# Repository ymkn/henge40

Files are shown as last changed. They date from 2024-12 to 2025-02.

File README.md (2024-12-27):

# Henge40

A compact 40% keyboard with 12-column row staggered layout in 12.75u width.

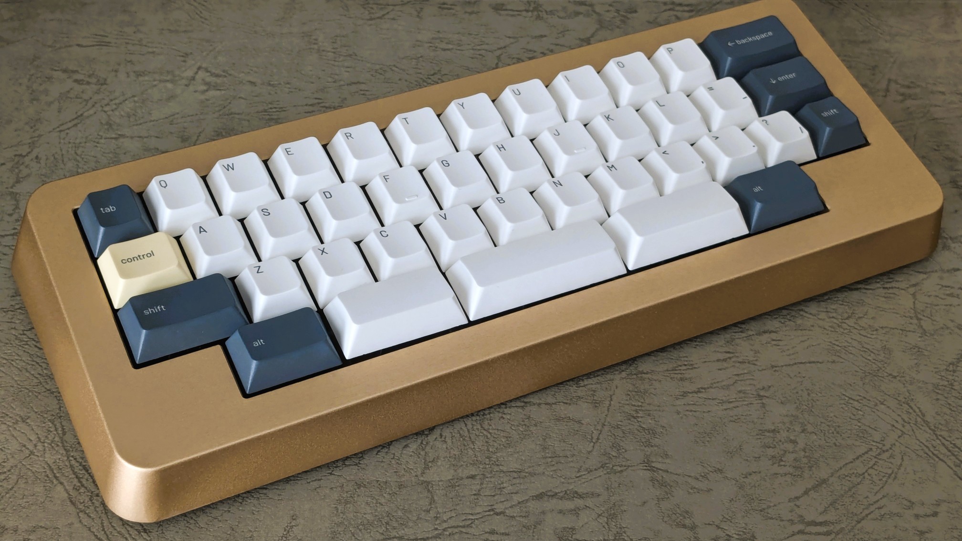
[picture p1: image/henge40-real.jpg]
Henge40 real image


This keyboard was inspired by [Menhir](https://fruitykeeb.xyz/collections/menhir-collection/products/gb-menhir).

## Default Layout

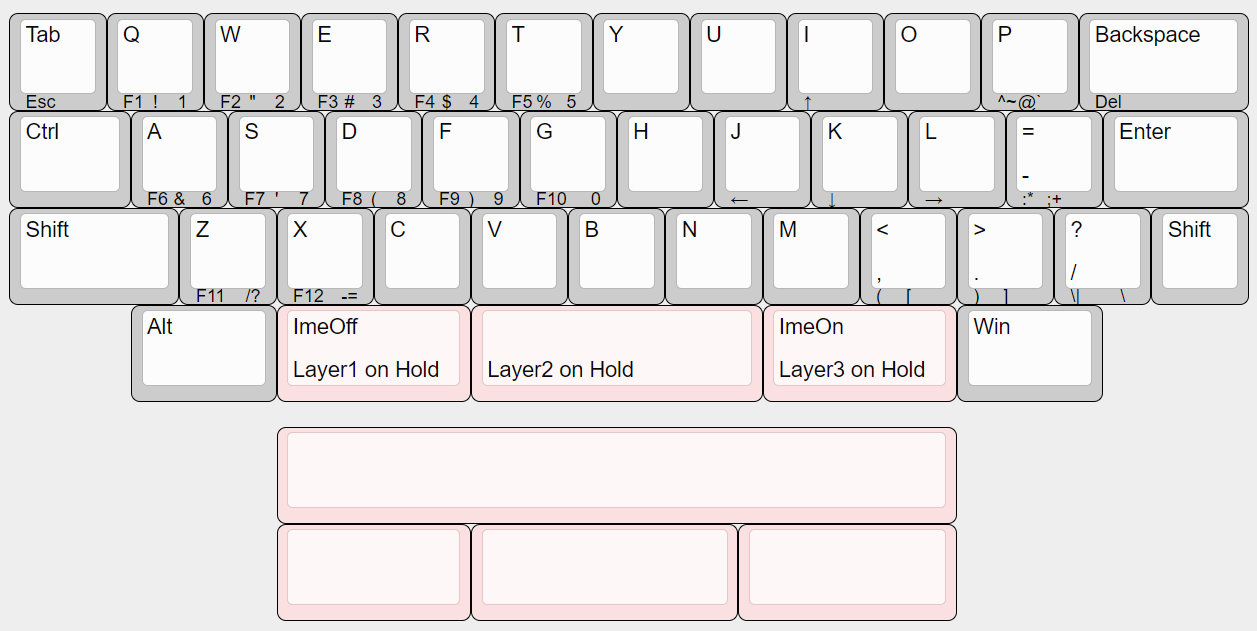
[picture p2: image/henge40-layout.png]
Henge40 layouts


You can also customize the layout using [Vial](https://get.vial.today/).

## Build Guide

See [Build Guide](doc/buildguide.md).

## License

This project is licensed under the MIT License, see the [LICENSE file](LICENSE) for details.

However, this does not apply to logo data (image files, KiCAD footprints, etc.) included in the resources of this project. Please contact us for secondary use.

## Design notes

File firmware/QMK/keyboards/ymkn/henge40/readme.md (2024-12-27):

# Henge40

Henge40 - A compact 40% keyboard with 12-column row staggered layout in 12.75u width.

* Keyboard Maintainer: [ymkn](https://github.com/ymkn)

Make example for this keyboard (after setting up your build environment):

    make ymkn/henge40:vial

Flashing example for this keyboard:

1. Enter the bootloader.
2. Simply copy ymkn_henge40_vial.uf2 to RPI_RP2 drive.

This keyboard supports [Vial](https://get.vial.today/) configurator.

## Bootloader

Enter the bootloader in 2 ways:

* **Bootmagic reset**: Hold down the key at (0,0) and (1,11) in the matrix (usually the top left key or Tab and the right 2nd top key or Enter) and plug in the keyboard
* **Physical reset button**: Briefly press the button on the daughterboard

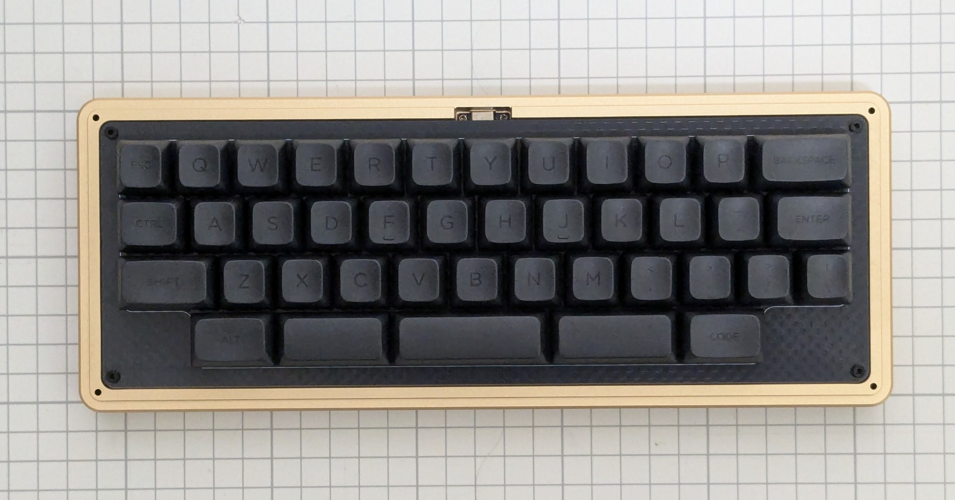
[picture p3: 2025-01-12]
image/henge40-keycap.jpg

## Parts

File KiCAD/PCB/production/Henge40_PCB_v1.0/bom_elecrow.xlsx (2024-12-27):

*Reference | *Manufacturer Part number | *QTY | *Original | Description | Purchase Link
D1, D10, D11, D12, D13, D14, D15, D16, D17, D18, D19, D2, D20, D21, D22, D23, D24, D25, D26, D27, D28, D29, D3, D30, D31, D32, D33, D34, D35, D36, D37, D38, D39, D4, D40, D41, D5, D6, D7, D8, D9 | 1N4148W | 41 | N
SW1, SW2, SW3, SW10, SW11, SW12, SW13, SW14, SW15, SW16, SW17, SW18, SW19, SW20, SW21, SW21_1, SW22, SW23, SW24, SW25, SW26, SW27, SW28, SW29, SW30, SW31, SW31_1, SW32, SW33, SW34, SW35, SW36, SW37, SW38, SW39, SW4, SW40, SW41, SW5, SW6, SW7, SW8, SW9 | CPG151101S11 | 43 | N | SKU: CRP13070O | https://www.elecrow.com/kailh-pcb-socket-sip-socket-hot-swappable-hot-plug-cpg151101s11-for-mechanical-keyboard.html
Declare：
All ICs will be original even you selected Not original required.
Original: Y means must use the original brand model, N means that you can accept the substitutes with same spec

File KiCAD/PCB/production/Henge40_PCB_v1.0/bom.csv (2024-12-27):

Designator | Footprint | Quantity | Value | LCSC Part #
D1, D10, D11, D12, D13, D14, D15, D16, D17, D18, D19, D2, D20, D21, D22, D23, D24, D25, D26, D27, D28, D29, D3, D30, D31, D32, D33, D34, D35, D36, D37, D38, D39, D4, D40, D41, D5, D6, D7, D8, D9 | D_SOD-123 | 41 | 1N4148W
SW1, SW10, SW11, SW12, SW13, SW14, SW15, SW16, SW17, SW18, SW19, SW20, SW21, SW21_1, SW22, SW23, SW24, SW25, SW26, SW27, SW28, SW29, SW30, SW31, SW31_1, SW32, SW33, SW34, SW36, SW37, SW38, SW4, SW41, SW5, SW6, SW8, SW9 | SW_MX_HS_CPG151101S11_1u | 37 | SW_Push
SW2 | SW_MX_HS_CPG151101S11_1.25u | 1 | SW_Push
SW3, SW39 | SW_MX_HS_CPG151101S11_1.75u | 2 | SW_Push
SW35, SW40, SW7 | SW_MX_HS_CPG151101S11_1.5u | 3 | SW_Push

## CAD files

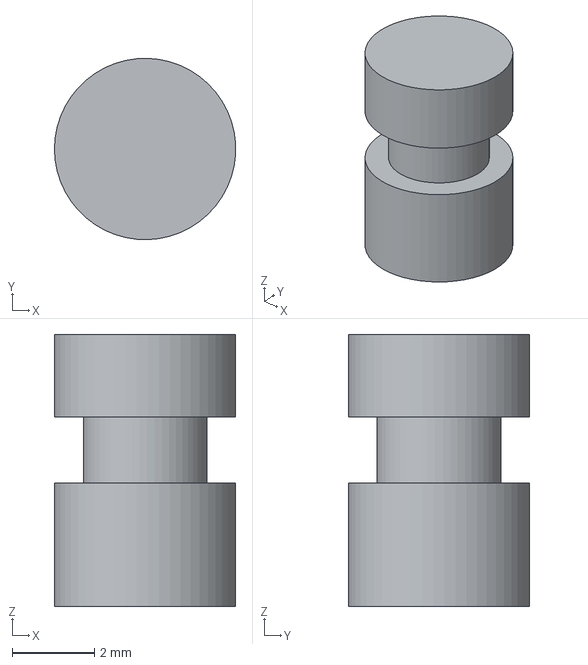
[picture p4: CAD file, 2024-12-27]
FreeCAD/DampingBall-Body.step
4.40 x 4.40 x 6.60 mm

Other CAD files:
FreeCAD/DampingBall.FCStd

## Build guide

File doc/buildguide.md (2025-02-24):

# Henge40ビルドガイド

## 1. 本書について

本書は自作キーボードHenge40キットのビルドガイドです。

## 2. 準備

### 2.1 内容物の確認

製品到着後すぐに内容物を確認し、不足や破損があった場合は保証期間内に[お問い合わせ先](https://ymkn.github.io/1u-nekokey/support/)までお寄せください。

※販売品に注記がある場合はそちらを正としてください。

|番号|品目|数量|
|---|---|---|
|1|Henge40 スイッチプレート|1枚|
|2|Henge40 メイン基板|1枚|
|3|Henge40 ドーターボード|1枚 (取付済)|
|4|Henge40 ケース (ボトム/トップ)|1セット|
|5|Henge40 スイッチフォーム|1枚|
|6|Henge40 スイッチパッド|1枚|
|7|Henge40 ケースフォーム|1枚|
|8|FPCケーブル 150mm 8ピン 1mmピッチ|1+1(予備)本|
|9|M2ねじ 4mm|8個 (取付済)|
|10|Damping Ball|4個 (取付済)|
|11|ゴム足（小）|4個|
|12|ゴム足（大） ※Flatケースにのみ付属|2個|

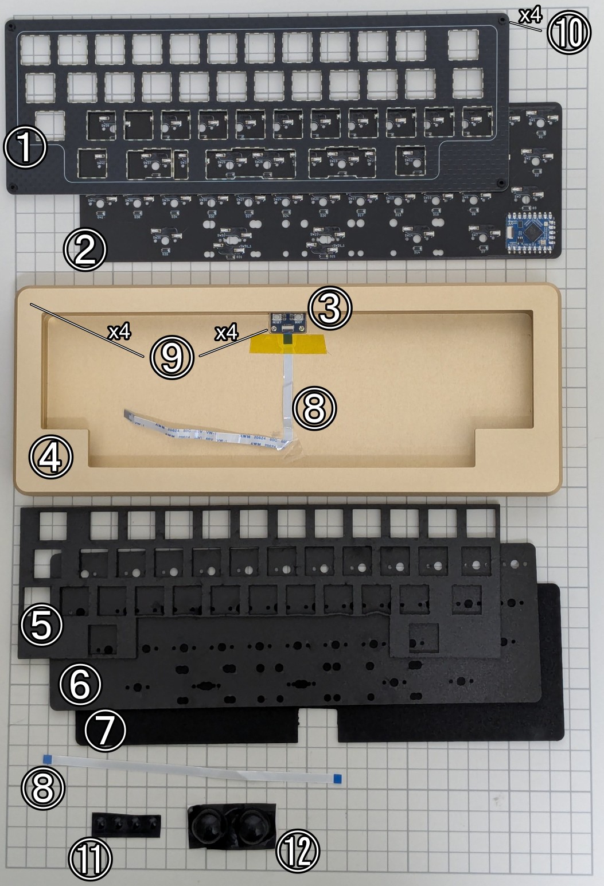
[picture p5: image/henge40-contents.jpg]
Henge40内容物


### 2.2 別途用意が必要な部品

下記は本キットに含まれません。国内外の自作キーボード専門店や電子部品販売店などから別途調達してください。

|品目|数量|備考|
|---|---|---|
|MX互換キースイッチ|39-41|[Cherry MX](https://www.cherry.de/en-gb/gaming/developer)もしくはその互換品|
|MX互換キーキャップ|必要数|[Cherry MX](https://www.cherry.de/en-gb/gaming/developer)もしくはその互換品|
|2uサイズPCBマウント型スタビライザー|2-3|幅の広いキーの押し下げを安定させる部品です。最下段で2u/2.75uキーを使う場合に必要です|
|3uサイズPCBマウント型スタビライザー|1|幅の広いキーの押し下げを安定させる部品です。最下段で3uキーを使う場合に必要です|
|7uサイズPCBマウント型スタビライザー|1|幅の広いキーの押し下げを安定させる部品です。最下段で7uキーを使う場合に必要です|

### 2.3 適合するキーキャップサイズ

下図の通りのキーキャップが必要です。赤網掛け部分は入れ替え可能な部分です。

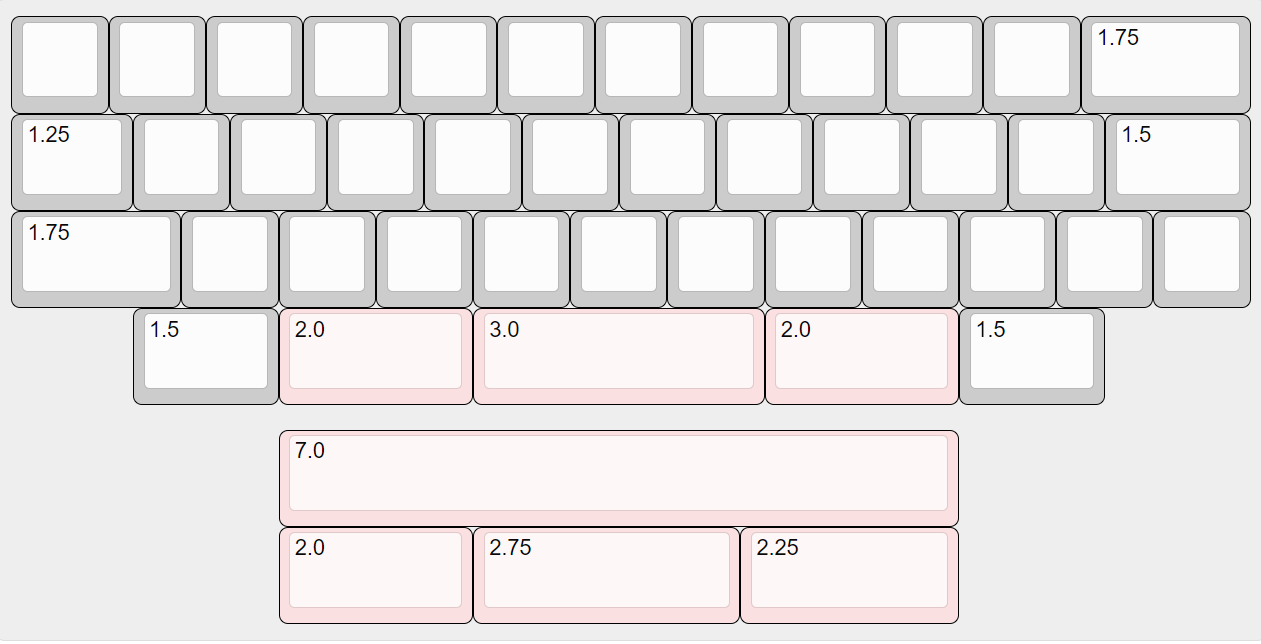
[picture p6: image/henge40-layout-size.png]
レイアウト


一般的なキーキャップセットには含まれないサイズがありますのでご購入の際はご注意ください。特に下記サイズは標準的なキーキャップセットに加えて別途40%用のキーキャップセットを入手する必要があります。

|行|サイズ|初期レイアウトの対応キー名|
|---|---|---|
|R1| - |※本キーボードにR1行はありません。最上段はR2行となります|
|R2|1u|Tabキー|
|R2|1.75u|Backspaceキー|
|R3|1.25u|Controlキー|
|R3|1.5u|Enterキー|
|R4|1.75u|Shiftキー|
|R4|1u|Shiftキー|
|R4|2u x 2, 2.75u, 3u, 7u|スペースキー|

上に示したキー名はあくまで初期レイアウトのもので、これはお好みに変更可能です。また、キーキャップの印字はただの飾りですので、同じ行の同じサイズのキーキャップであれば異なる印字のキーキャップでもお使いいただけます。

> [!TIP]
> 自分でデザインしたキーキャップセットを購入できるサービス[YUZU Custom Keycaps](https://yuzukeycaps.com/)の40%キットにて、必要なキーが全て揃います。参考までに作者が展示用にデザインした[Henge40 Yozora](https://yuzukeycaps.com/c/3475d350-a4f5-4abe-b16b-a6b00855d77e)テンプレートをカスタマイズして発注するのも良いかと思います。

### 2.3 道具

以下の道具が必要です。

|品目|数量|備考|
|---|---|---|
|ねじ回し（プラス、M2用1番）|1|ケースを固定する際に用います|

## 4. 組み立て

### 4.1 メイン基板の準備

> [!CAUTION]
> まず作業を始める前に、メイン基板のウラ面にあるFPCケーブルコネクタの羽が水平方向に閉じていることを確認します。これが垂直方向に開いた状態で後続の作業を行うと羽が破損する可能性があります。
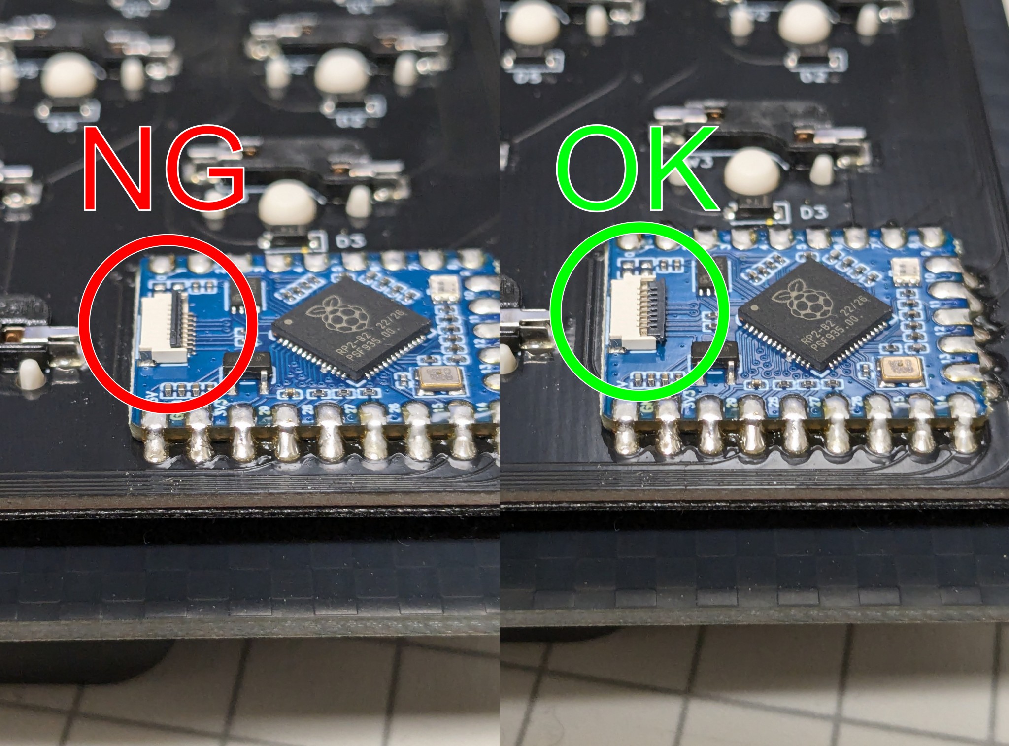
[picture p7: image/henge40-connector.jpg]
> 
> ロットによっては羽が内側ではなく外側に付いている場合もあります。こちらも同様に水平方向に閉じていることを確認してください。
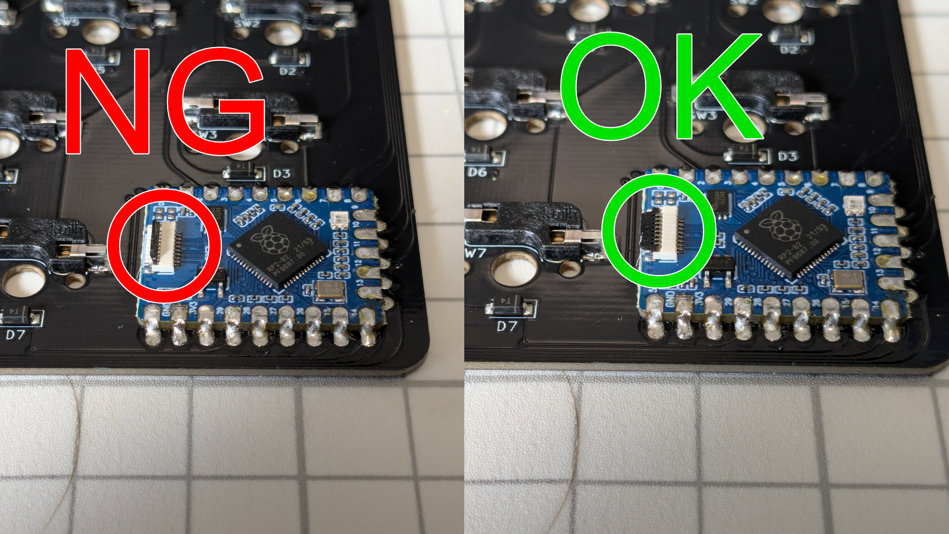
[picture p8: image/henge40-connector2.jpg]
> 

確認出来たら、**オモテ面**が上になるようにメイン基板を作業場所に配置します。

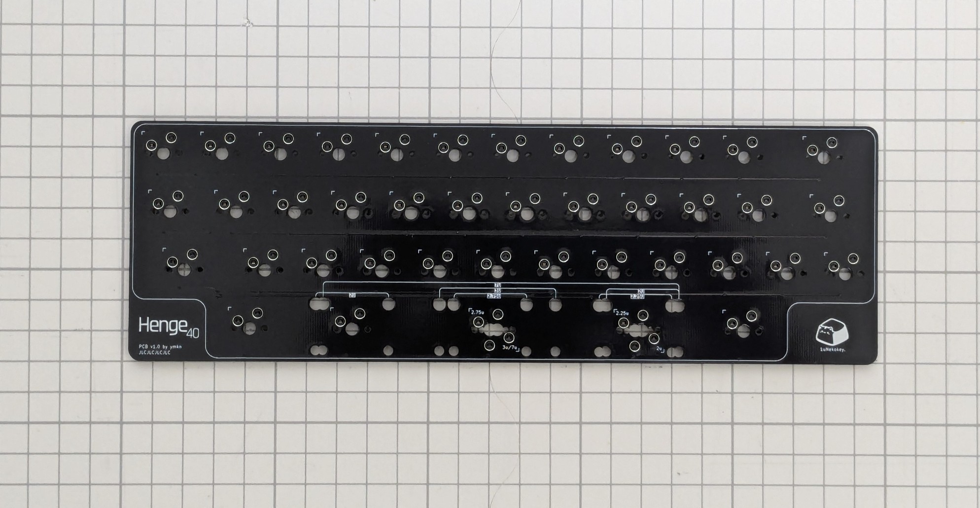
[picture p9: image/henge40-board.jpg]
基板表


### 4.2 スイッチパッドの取り付け

スイッチパッドを基板の上に設置してください。スイッチパッドと基盤の穴の位置を合わせて単純に乗せるだけでよいです。

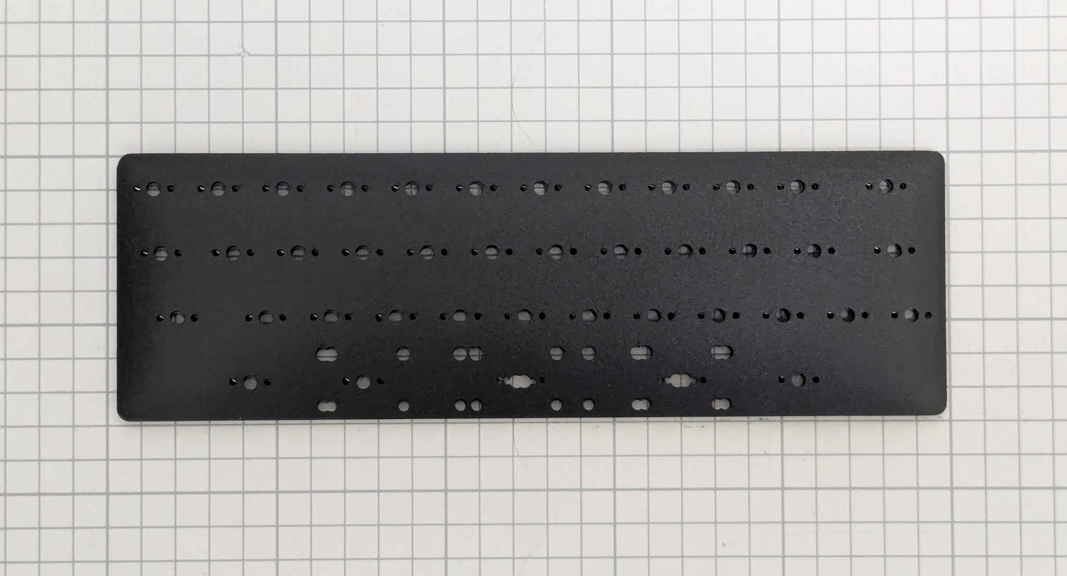
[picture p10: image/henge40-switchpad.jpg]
スイッチパッド


> [!TIP]
> スイッチパッドは打鍵音を低音寄りに変化させるための部品です。取り付けは任意ですが、取り付けない場合は1.2mm厚基板用スタビライザーを用いるか、1.6mm厚基板用スタビライザーにシム（0.4mm）を挟んで高さを調節してください。

### 4.3 スタビライザーの取り付け

スイッチパッドの上からスタビライザーを取り付けます。

取り付け位置はレイアウトによって異なります。メイン基板上のガイドを参照してください。

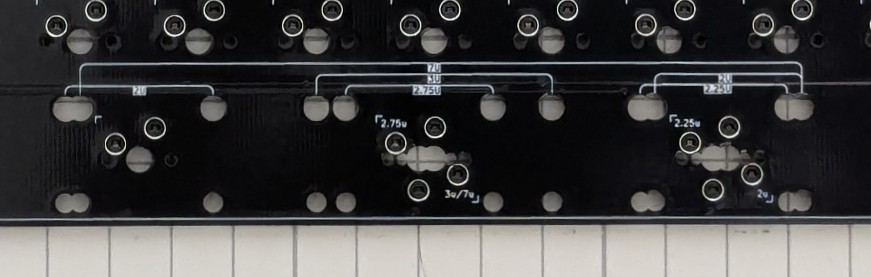
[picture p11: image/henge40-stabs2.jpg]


取り付け方はスタビライザーの説明書や世間の情報を参照ください。一般には大きい穴の方にツメを引っかけ、小さい穴の方にプッシュピンを差し込む、もしくはネジ留めを行うものが多いです。

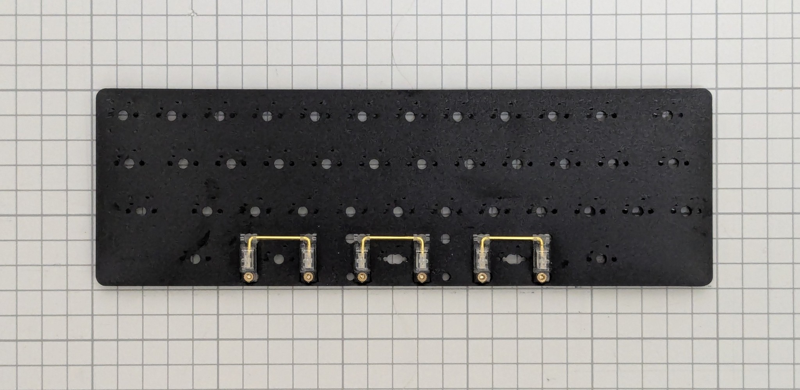
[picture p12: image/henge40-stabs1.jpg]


### 4.4 スイッチフォームの取り付け

スイッチパッドの上にスイッチフォームを乗せます。フォームの穴とスイッチの設置箇所が合う向きにしてください。

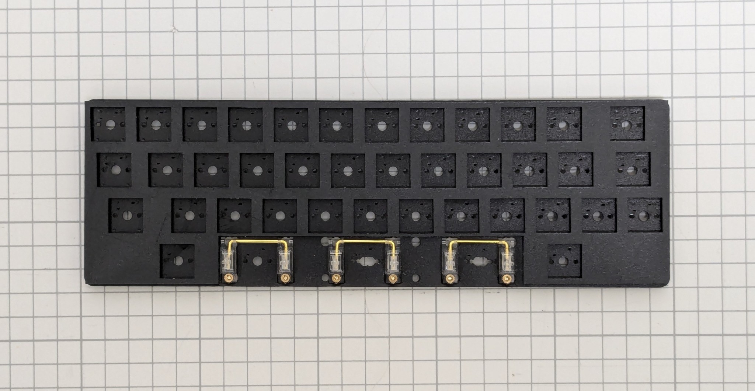
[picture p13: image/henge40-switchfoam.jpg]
スイッチフォーム


> [!TIP]
> スイッチフォームは打鍵音を小さくし反響音を抑えるための部品です。取り付けは任意です。

### 4.5 スイッチとスイッチプレートの取り付け

スイッチフォームの上にスイッチプレートを乗せ、その上からスイッチを基板のソケットに差し込みます。

差し込む前にスイッチの向きをよく確認してください。ほとんどのスイッチは南向き（ピンがキーボードの奥側向き）ですが、採用レイアウトによっては最下段に北向きの場所があります。誤った向きに押し込んでピンを曲げてしまった場合は、ラジオペンチなどで伸ばしてください。

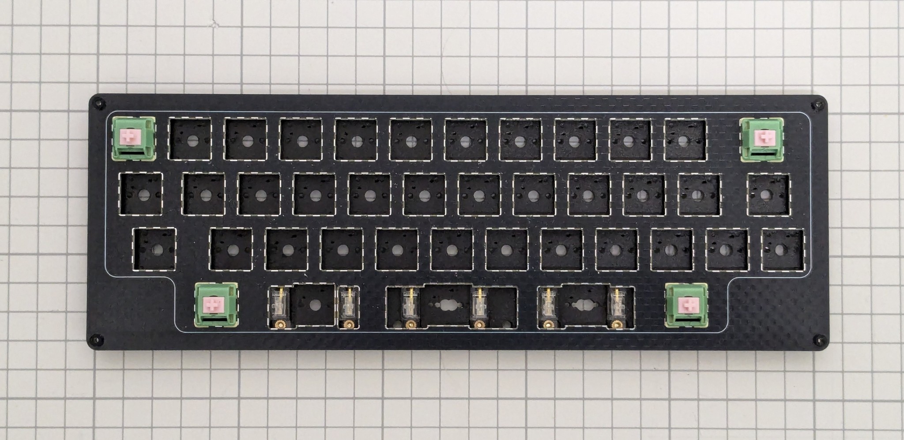
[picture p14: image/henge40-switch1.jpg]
スイッチ取り付け1


先に四隅に取り付けると作業しやすいです。

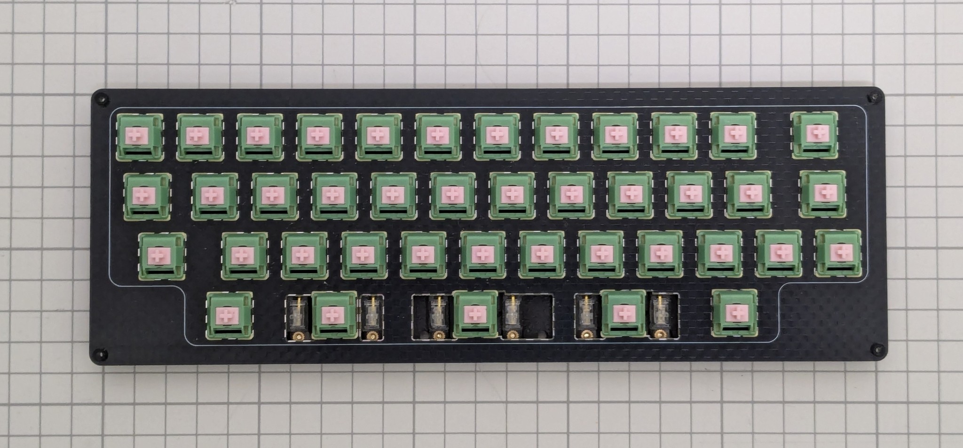
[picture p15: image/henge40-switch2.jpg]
スイッチ取り付け2


### 4.6 ケースフォームの取り付け

ケース底面四隅のネジをはずして、ケースの蓋を外します。切り欠きの位置を合わせてケースに乗せてください。

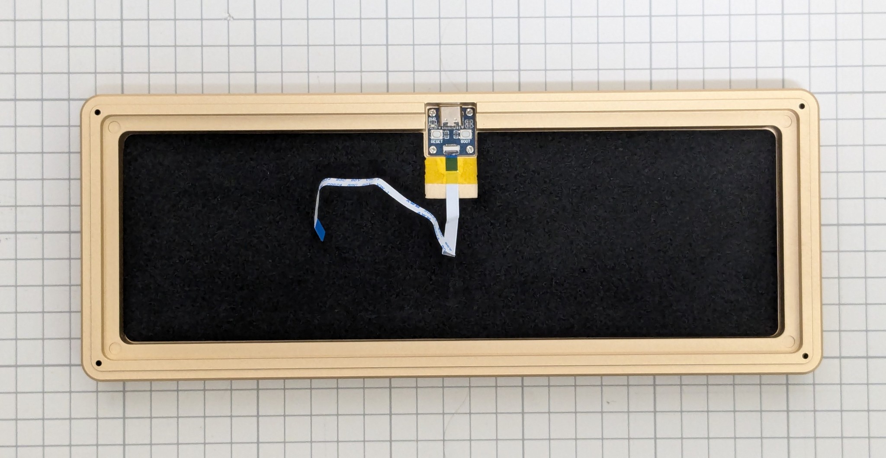
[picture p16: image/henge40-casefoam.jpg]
ケースフォーム


> [!TIP]
> ケースフォームは打鍵音の反響を抑えるほか、万一基盤とケースが触れた場合のショートを防止する役割があります。打鍵音の調整のために取り付けない場合は、代わりに絶縁可能な素材を敷いてください。

なお、ドーターボードの上に保護用フォームが取り付けてある場合は取り除いてください。

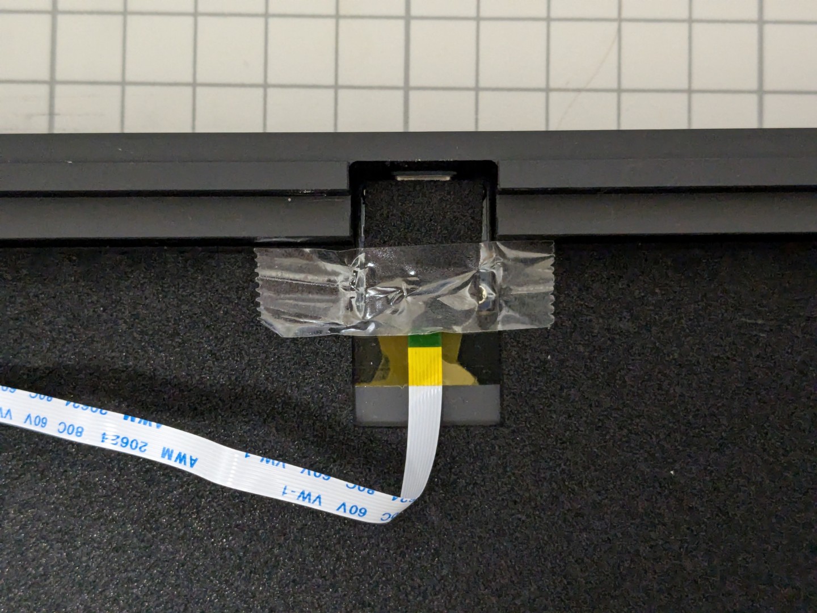
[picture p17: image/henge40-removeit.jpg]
保護フォーム


### 4.7 メイン基板とドーターボードの接続

メイン基板とドーターボードをFPCケーブルで接続します。

> [!WARNING]
> FPCケーブルを接続する**コネクタは非常に壊れやすい**部分です。無理な力を加えないように注意して作業してください。コネクタを折ってしまった場合はケーブル接続が不可能となり、キーボードとして使用できなくなってしまいます。

FPCコネクタ（黒い羽根）を垂直に立つように跳ね上げます。

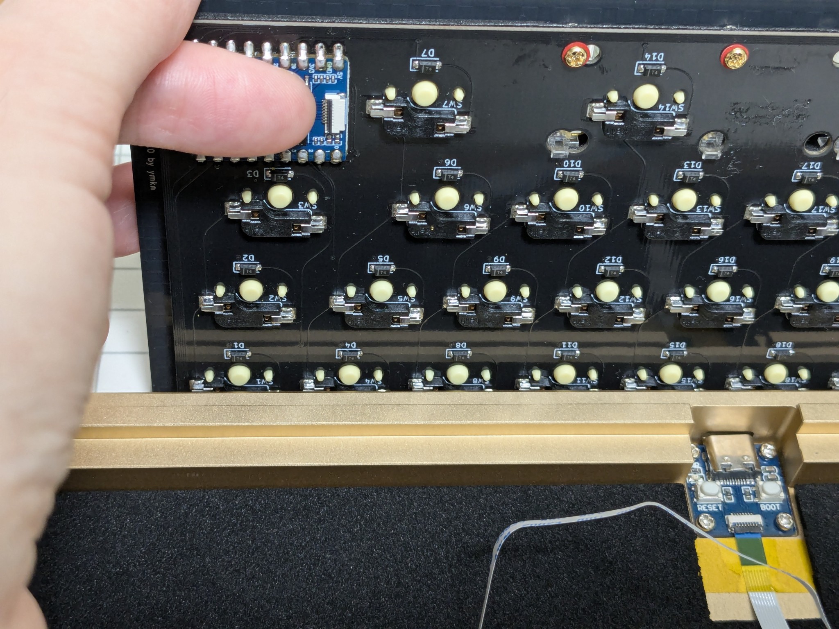
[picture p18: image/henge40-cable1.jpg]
FPC接続1


FPCケーブルの青色の面を上にしてコネクタに差し込みます（1mm弱ほどは刺さるはずです）。

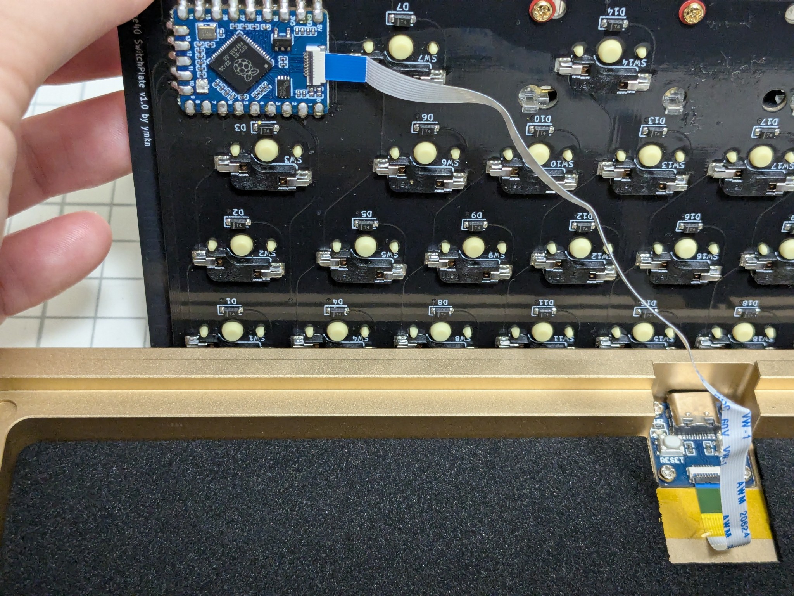
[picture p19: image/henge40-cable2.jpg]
FPC接続2


ケーブルがまっすぐに刺さっていることを確認し、コネクタの羽を元に戻して固定します。ケーブルを軽く引っ張って、抜けないことを確認してください。

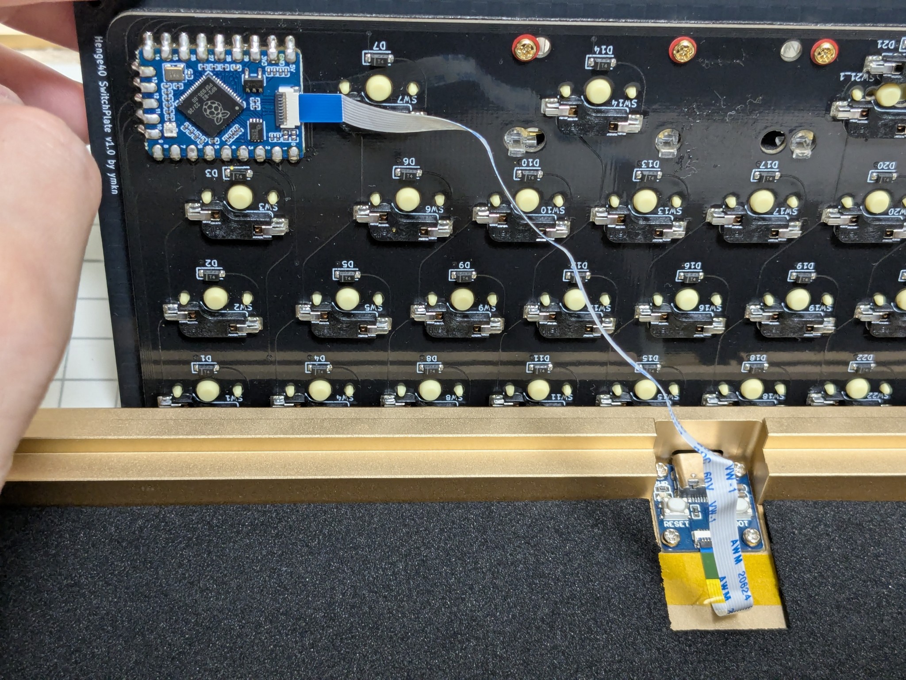
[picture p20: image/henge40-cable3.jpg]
FPC接続3


> [!TIP]
> ここでFPCケーブルをメイン基板にテープ等で固定しておくと、打鍵時にケーブルがメイン基板にぶつかってカチャカチャ音が鳴るのを防げます。
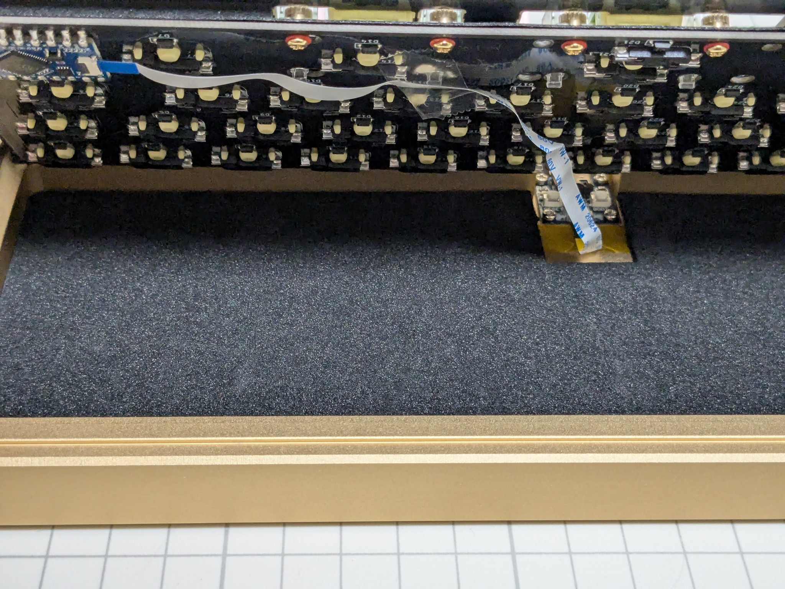
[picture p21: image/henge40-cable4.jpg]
FPC接続4


ケーブルが接続できたら、メイン基板をケースの上に置いてください。スイッチプレート四隅のゴム足が、ケースの丸い溝に入るようにします。

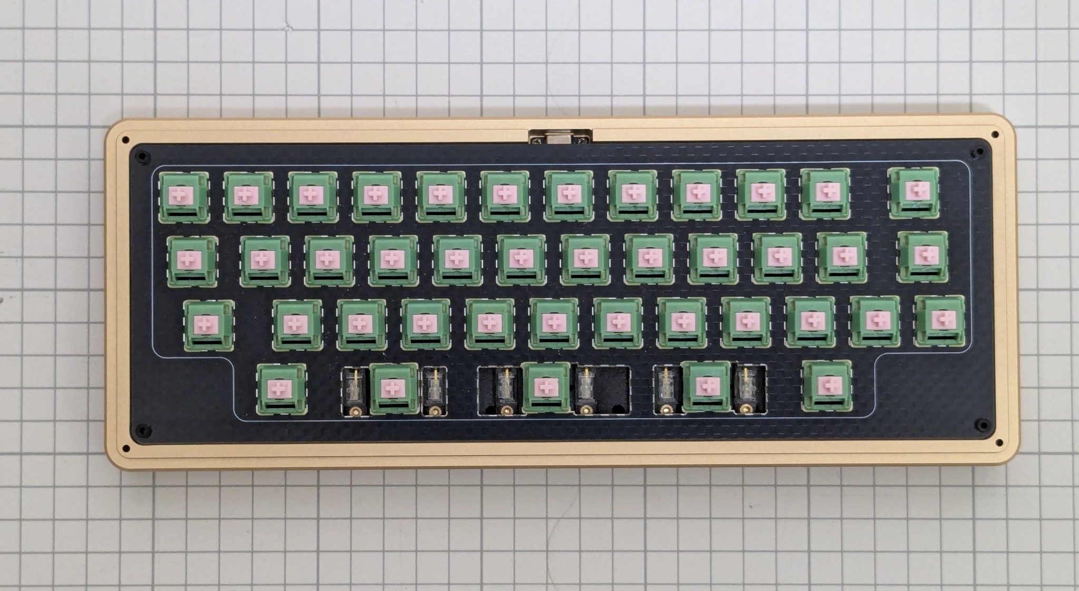
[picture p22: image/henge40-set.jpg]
ケースに設置


### 4.8 ケースのネジ留め

> [!CAUTION]
> ケースをひっくり返す際にうっかり基板を落下させてしまうと、ケーブルが強く引っ張られてコネクタを破損させてしまう可能性があります。そうならないよう慎重に行ってください。

上蓋と基板が落下しないように支えながらケースをひっくり返し、ケース底部四隅の穴にネジを入れてネジ留めを行ってください。

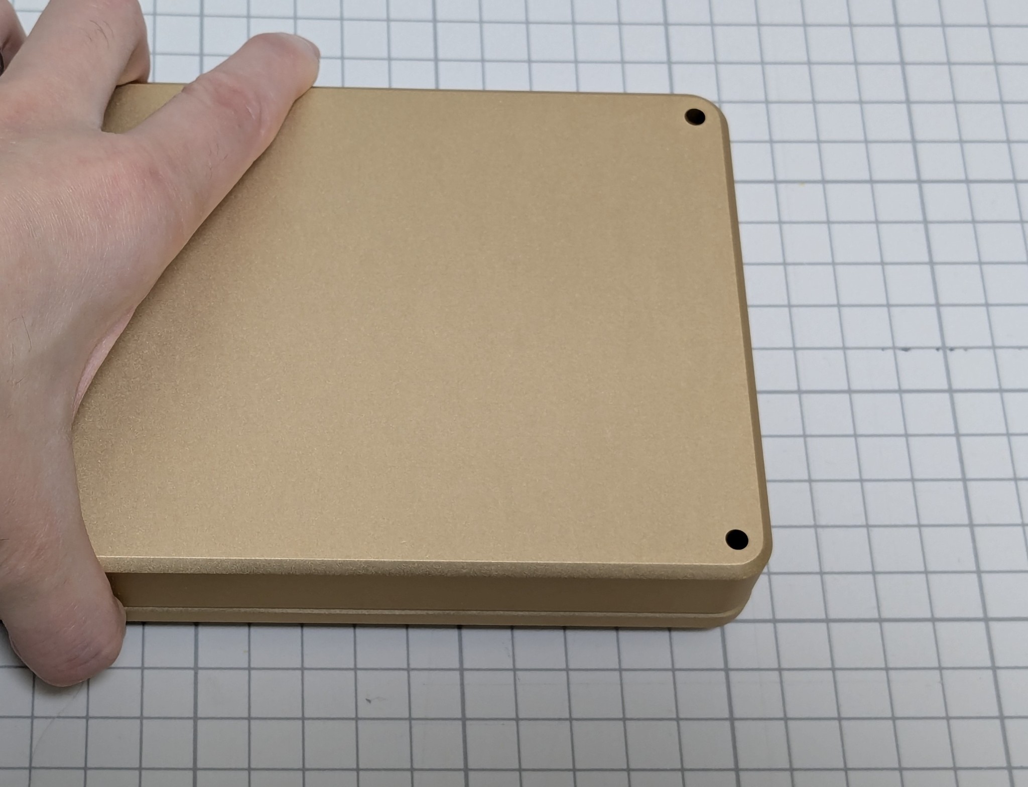
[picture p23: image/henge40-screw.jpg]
ケースのネジ留め


このとき、強い力でネジを締めつけ過ぎないように注意してください。軽い力でネジを回していって、抵抗感が増して動きにくくなるあたりで十分です。

ネジが締まったら、お好みでゴム足を取り付けてください。

### 4.10 キーキャップの取り付け

ケースの向きをもとに戻し、全てのスイッチにキーキャップを取り付けてください。

> [!TIP]
> スタビライザーのあるキーキャップは、深く押し込み過ぎると戻りにくくなることがあります。スイッチのある中央部分だけを押し込んで取り付けるようにするとよいでしょう。

すべて取り付けられたら完成です。

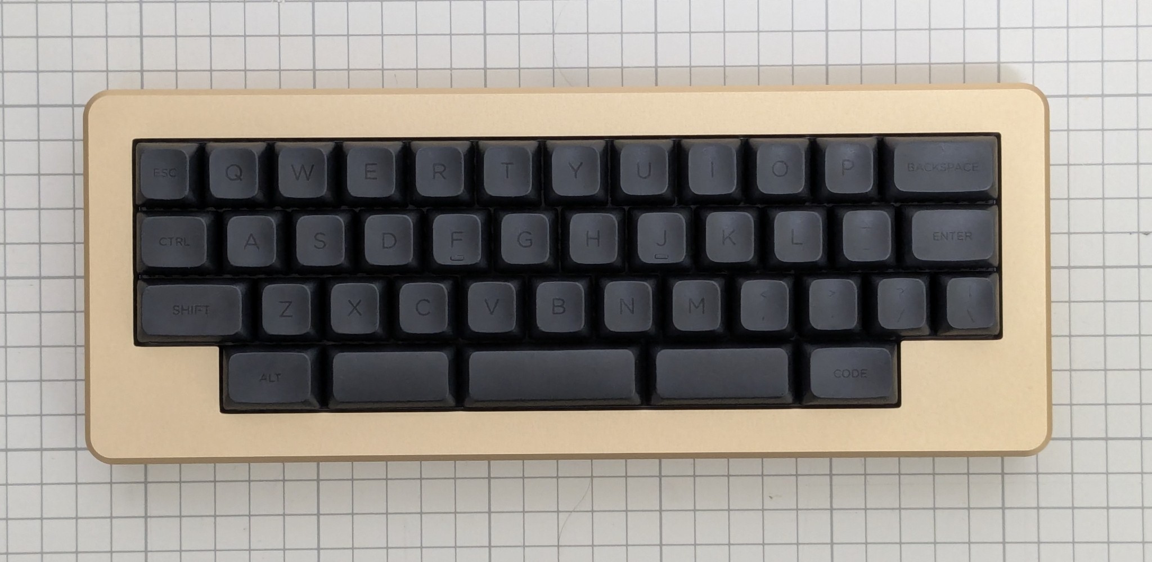
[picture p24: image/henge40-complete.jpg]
完成


## 5. 使用

### 5.1 動作確認

コンピュータとHenge40をUSBケーブルで接続し、キーボードとして認識され、文字が入力できることを確認してください。

キーボードとして認識されない場合は、FPCケーブルが外れていたりズレていたりする可能性があります。メイン基板側とドーターボード側の両方が適切に接続されていることを確認してください。また、FPCケーブルを何度も強く曲げた場合など断線している可能性があります。そのような場合は予備のケーブルに交換してください。

一部のキーのみ反応しない場合は、そのキースイッチを抜いて、スイッチのピンが曲がっていないか確認してから挿し直してみてください。ピンが曲がっていない場合でも接触が悪いせいで動かないケースもあります。

### 5.2 キーマップのカスタマイズ

本キーボードは[Vial](https://get.vial.today/)というキーマップ変更ツールに対応しています。Vialの詳しい使いかたはVialのドキュメント等を参考にしてください。

> [!TIP]
> 何らかの理由で既定のレイアウトに戻したい場合は、本書末尾記載の「ブートモードの入り方」に従いブートモードに入った後、再度USBケーブルを抜き差しすることで初期化されます。

## 6. その他

### 6.1 ブートモードの入り方

ブートモードに入るには、USBケーブルを切断してから、左上のキー（Tabキー）を押しながらUSBケーブルを接続します。

もしくは、USBケーブルを接続した状態でドーターボード上のBOOTボタンを押しながらRESETボタンを押します。

### 6.2 ソースコード/設計データのありか

本リポジトリ内で公開しています。MITライセンスです。

https://github.com/ymkn/henge40

### 6.3 ファームウェアの書き込み

何らかの理由でファームウェアを書き込み直したい場合は下記からファームウェアをダウンロードしてください。

https://github.com/ymkn/henge40/releases/download/v1.0/ymkn_Henge40_vial.uf2

### 6.4 お問い合わせ

[サポートポリシー](https://ymkn.github.io/1u-nekokey/support/)をご参照のうえ、お問い合わせください。ポリシーに適合しないお問い合わせについてはお受けしておりません。

Henge40キットに関わるご質問はご購入されたアカウントにてログイン後、[BOOTH](https://ymkn.booth.pm/)のメッセージ欄までお願いいたします。

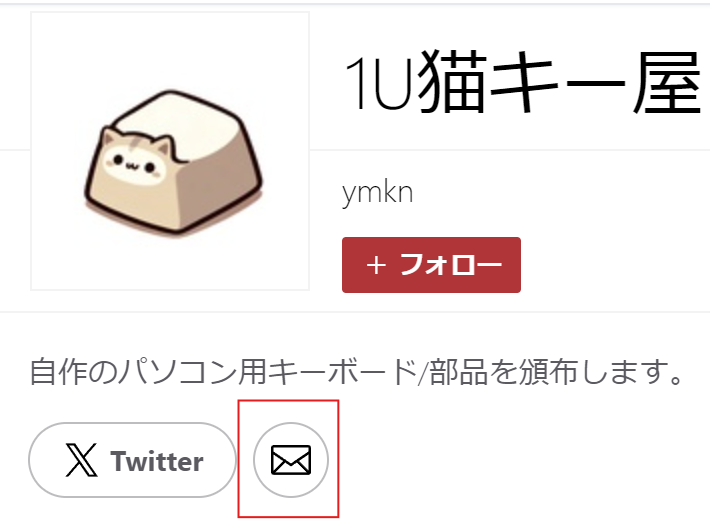
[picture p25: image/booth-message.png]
BOOTHメッセージ欄


キーケット等で直接購入された方でBOOTHのアカウントをお持ちでない場合は、私のTwitterアカウント[@ymkn_gbf](https://x.com/ymkn_gbf)でも受け付けます。メンションもしくはDMをください。

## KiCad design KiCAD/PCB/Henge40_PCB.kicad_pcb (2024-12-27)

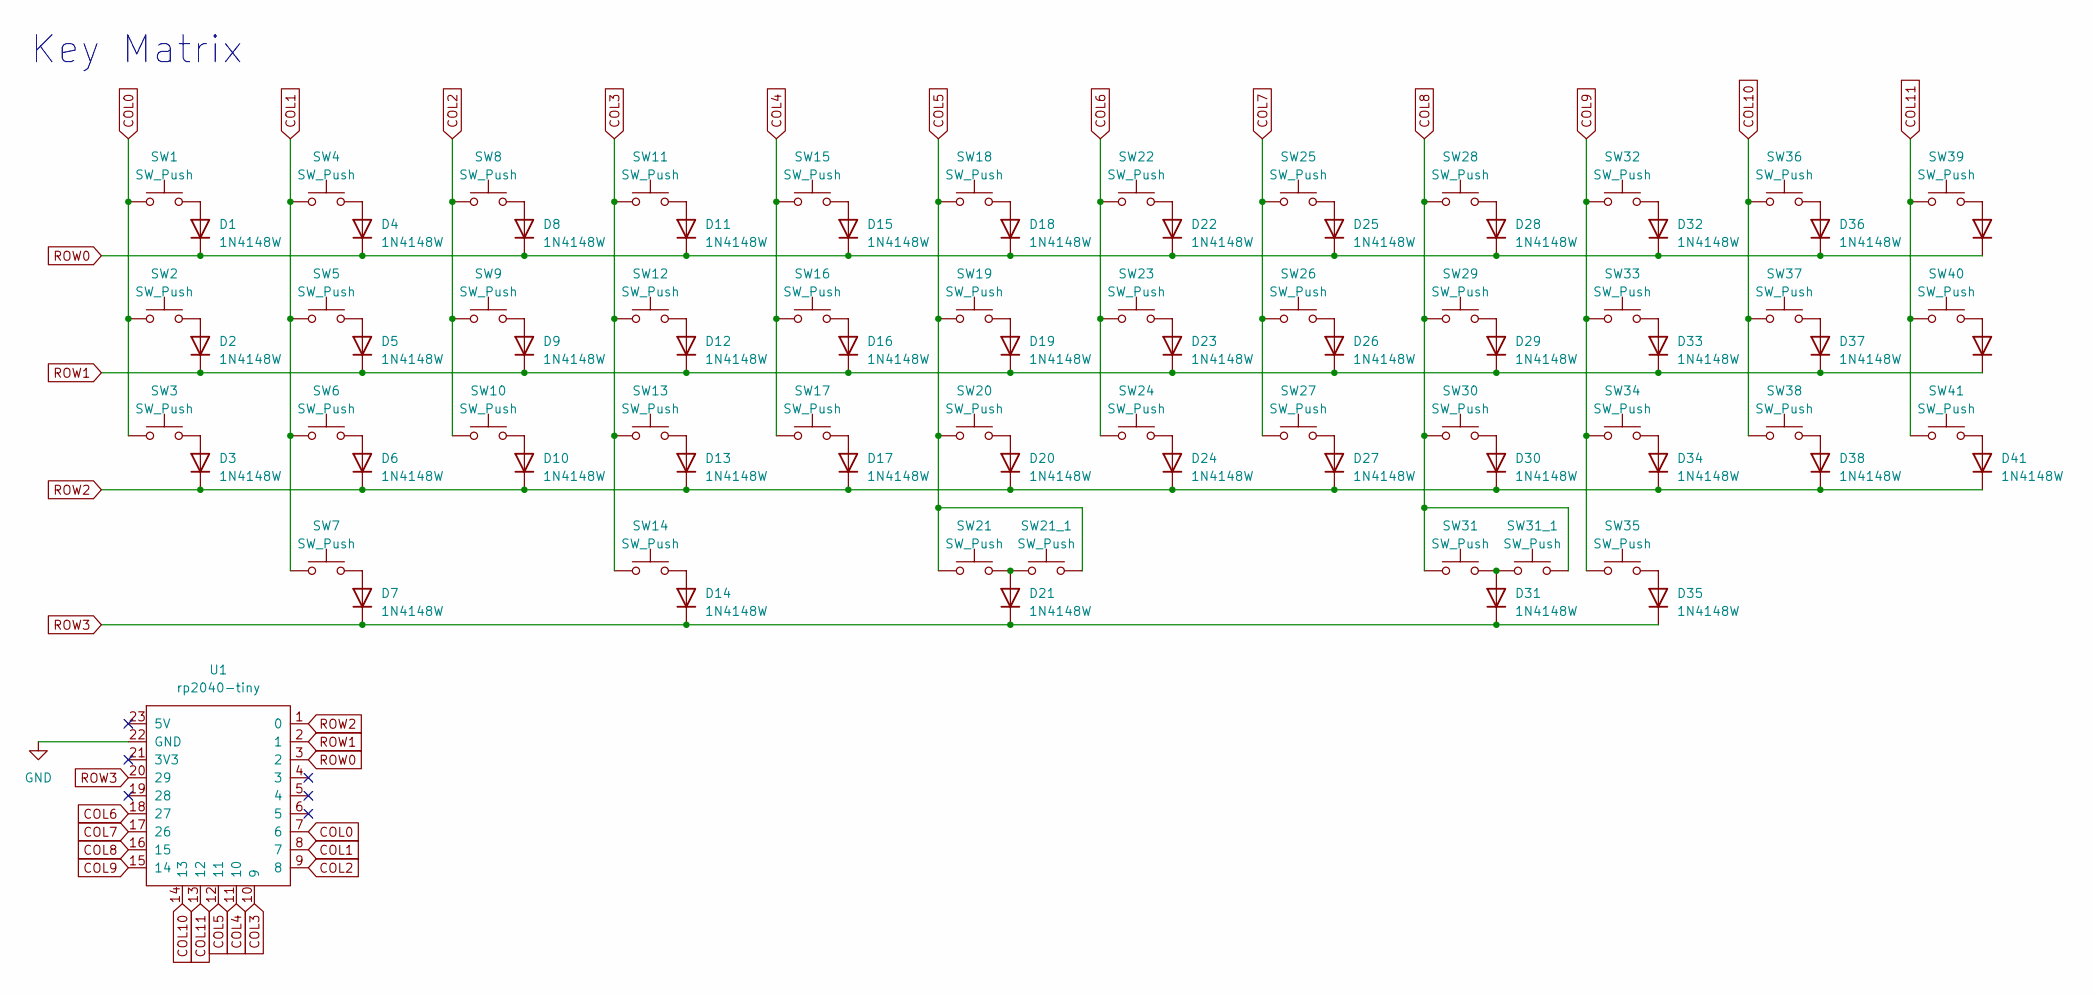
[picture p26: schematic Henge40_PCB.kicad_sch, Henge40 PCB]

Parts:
D1, D2, D3, D4, D5, D6, D7, D8, D9, D10, D11, D12, D13, D14, D15, D16, D17, D18, D19, D20, D21, D22, D23, D24, D25, D26, D27, D28, D29, D30, D31, D32, D33, D34, D35, D36, D37, D38, D39, D40, D41: 1N4148W; D_SOD-123; LCSC Parts # C81598
SW1, SW4, SW5, SW6, SW8, SW9, SW10, SW11, SW12, SW13, SW14, SW15, SW16, SW17, SW18, SW19, SW20, SW21, SW21_1, SW22, SW23, SW24, SW25, SW26, SW27, SW28, SW29, SW30, SW31, SW31_1, SW32, SW33, SW34, SW36, SW37, SW38, SW41: SW_Push; SW_MX_HS_CPG151101S11_1u; LCSC Parts # C18212911
SW2: SW_Push; SW_MX_HS_CPG151101S11_1.25u; LCSC Parts # C18212911
SW3, SW39: SW_Push; SW_MX_HS_CPG151101S11_1.75u; LCSC Parts # C18212911
SW7, SW35, SW40: SW_Push; SW_MX_HS_CPG151101S11_1.5u; LCSC Parts # C18212911
U1: rp2040-tiny; Waveshare_RP2040-Zero_SMD

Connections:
COL0: SW1.1, SW2.1, SW3.1, U1.7 (6)
COL1: SW4.1, SW5.1, SW6.1, SW7.1, U1.8 (7)
COL2: SW8.1, SW9.1, SW10.1, U1.9 (8)
COL3: SW11.1, SW12.1, SW13.1, SW14.1, U1.10 (9)
COL4: SW15.1, SW16.1, SW17.1, U1.11 (10)
COL5: SW18.1, SW19.1, SW20.1, SW21.1, SW21_1.2, U1.12 (11)
COL6: SW22.1, SW23.1, SW24.1, U1.18 (27)
COL7: SW25.1, SW26.1, SW27.1, U1.17 (26)
COL8: SW28.1, SW29.1, SW30.1, SW31.1, SW31_1.2, U1.16 (15)
COL9: SW32.1, SW33.1, SW34.1, SW35.1, U1.15 (14)
COL10: SW36.1, SW37.1, SW38.1, U1.14 (13)
COL11: SW39.1, SW40.1, SW41.1, U1.13 (12)
GND: U1.22 (GND)
unnamed: D1.2 (A), SW1.2
unnamed: D2.2 (A), SW2.2
unnamed: D3.2 (A), SW3.2
unnamed: D4.2 (A), SW4.2
unnamed: D5.2 (A), SW5.2
unnamed: D6.2 (A), SW6.2
unnamed: D7.2 (A), SW7.2
unnamed: D8.2 (A), SW8.2
unnamed: D9.2 (A), SW9.2
unnamed: D10.2 (A), SW10.2
unnamed: D11.2 (A), SW11.2
unnamed: D12.2 (A), SW12.2
unnamed: D13.2 (A), SW13.2
unnamed: D14.2 (A), SW14.2
unnamed: D15.2 (A), SW15.2
unnamed: D16.2 (A), SW16.2
unnamed: D17.2 (A), SW17.2
unnamed: D18.2 (A), SW18.2
unnamed: D19.2 (A), SW19.2
unnamed: D20.2 (A), SW20.2
unnamed: D21.2 (A), SW21.2, SW21_1.1
unnamed: D22.2 (A), SW22.2
unnamed: D23.2 (A), SW23.2
unnamed: D24.2 (A), SW24.2
unnamed: D25.2 (A), SW25.2
unnamed: D26.2 (A), SW26.2
unnamed: D27.2 (A), SW27.2
unnamed: D28.2 (A), SW28.2
unnamed: D29.2 (A), SW29.2
unnamed: D30.2 (A), SW30.2
unnamed: D31.2 (A), SW31.2, SW31_1.1
unnamed: D32.2 (A), SW32.2
unnamed: D33.2 (A), SW33.2
unnamed: D34.2 (A), SW34.2
unnamed: D35.2 (A), SW35.2
unnamed: D36.2 (A), SW36.2
unnamed: D37.2 (A), SW37.2
unnamed: D38.2 (A), SW38.2
unnamed: D39.2 (A), SW39.2
unnamed: D40.2 (A), SW40.2
unnamed: D41.2 (A), SW41.2
ROW0: D1.1 (K), D4.1 (K), D8.1 (K), D11.1 (K), D15.1 (K), D18.1 (K), D22.1 (K), D25.1 (K), D28.1 (K), D32.1 (K), D36.1 (K), D39.1 (K), U1.3 (2)
ROW1: D2.1 (K), D5.1 (K), D9.1 (K), D12.1 (K), D16.1 (K), D19.1 (K), D23.1 (K), D26.1 (K), D29.1 (K), D33.1 (K), D37.1 (K), D40.1 (K), U1.2 (1)
ROW2: D3.1 (K), D6.1 (K), D10.1 (K), D13.1 (K), D17.1 (K), D20.1 (K), D24.1 (K), D27.1 (K), D30.1 (K), D34.1 (K), D38.1 (K), D41.1 (K), U1.1 (0)
ROW3: D7.1 (K), D14.1 (K), D21.1 (K), D31.1 (K), D35.1 (K), U1.20 (29)

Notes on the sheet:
Key Matrix

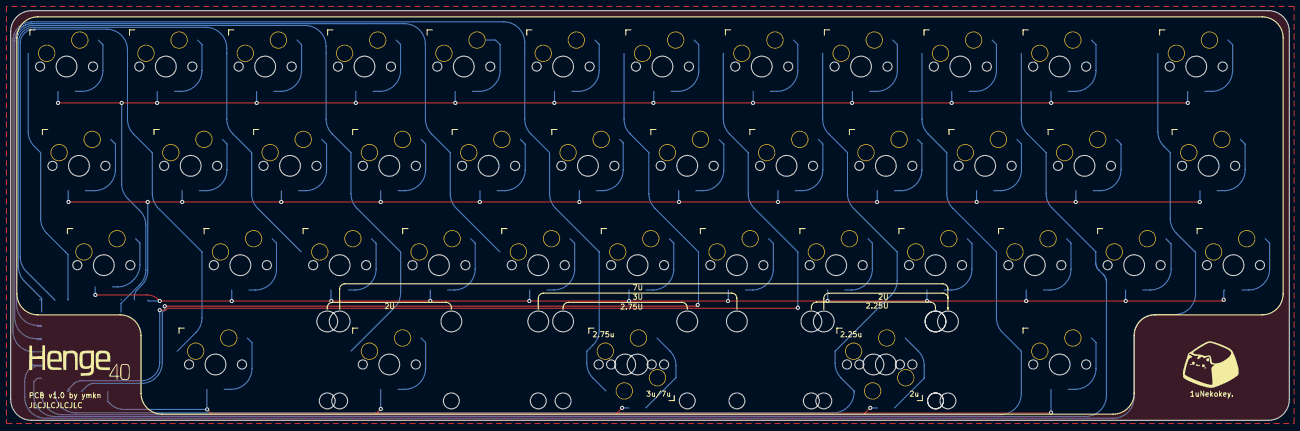
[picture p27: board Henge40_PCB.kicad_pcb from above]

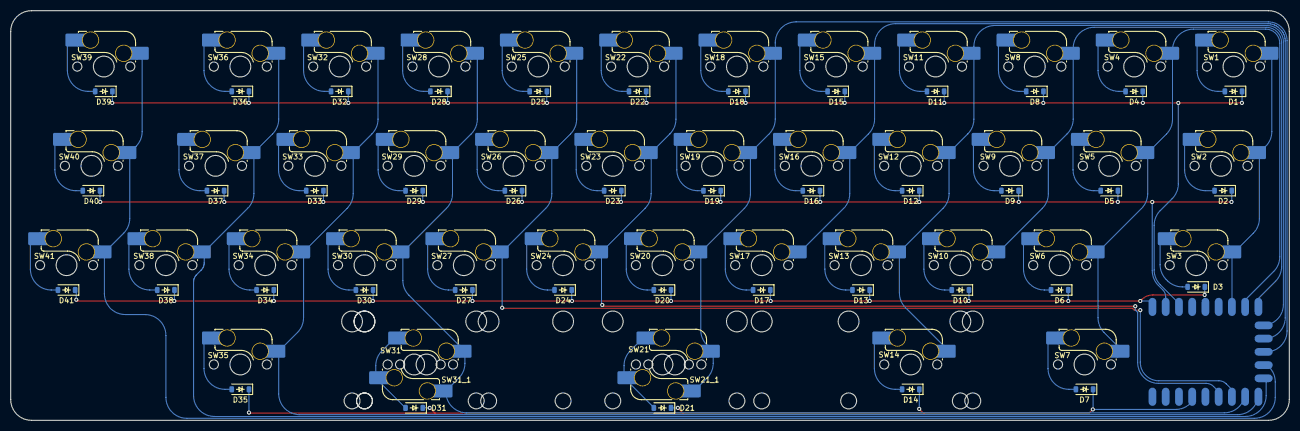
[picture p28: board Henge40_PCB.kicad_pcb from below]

Board: 2 copper layers, 245.3 x 78.6 mm, 85 parts (85 on the bottom side), 57 nets.

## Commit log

2024-10-28 submoduleの追加
2024-10-28 v1.0製造断面
    [Henge40_PCB.kicad_pcb, Henge40_PCB.kicad_sch]
2024-10-28 ファームウェア
2024-10-28 v1.1ケース製造データ
    [Henge40-thickness.xlsx, Henge40_Enclosure-Case.step, Henge40_Enclosure-Cover.step]
2024-10-28 READMEの修正
2024-12-27 最新のymknlibsに切り替え
2024-12-27 1stロット量産断面
    [Henge40-thickness.xlsx, Henge40_PCB.kicad_pcb, Henge40_PCB.kicad_sch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]
2024-12-27 READMEを整備
2024-12-27 ファームウェアのソースを追加
2024-12-27 移動元のファイルを削除
    [Henge40-thickness.xlsx, Henge40_Enclosure-Case.step, Henge40_Enclosure-Cover.step]
2024-12-27 Damping Ballのモデルを追加
    [DampingBall-Body.step, DampingBall.FCStd]
2024-12-27 ファームウェアのソースのREADMEを追加
2024-12-27 READMEの画像が荒かったのを修正
2025-01-12 ビルドガイドの追加
2025-01-12 v1.0断面
2025-01-13 脱字とBOOTHリンク修正
2025-01-13 ケース呼称の変更
2025-02-24 ロット違いの写真追加、サポートポリシーのリンク追加
